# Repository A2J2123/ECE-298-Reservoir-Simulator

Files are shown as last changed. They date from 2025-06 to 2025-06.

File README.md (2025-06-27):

# ECE-298 Reservoir Simulator

A comprehensive reservoir simulator system designed and built using an STM32 Nucleo board to emulate water flow management in a controlled reservoir environment.

---

## 🏗️ What is this project?

This project features a fully integrated reservoir simulation platform that:

- Measures real-time water level and displays the percentage full.
- Controls water flow direction and simulates water pumping.
- Monitors pump speed, indicates flow direction, and transmits live measurements to a computer via UART.
- Models practical water management and feedback control scenarios using embedded systems.

---

## ⚙️ How does it work?

The simulator is powered by an STM32 microcontroller, programmed in C, and incorporates:

- **Servo Motor:** Controls flow direction (simulates outlet switching).
- **DC Motor:** Drives the water pump, with speed monitored by an RPM sensor.
- **Ultrasonic Sensor:** Measures water level with high accuracy.
- **RGB LED:** Provides visual status indicators.
- **Custom Timer PCB:** Drives a seven-segment display for real-time feedback.
- **UART Connection:** Streams sensor data and system state to a computer for monitoring and analysis.

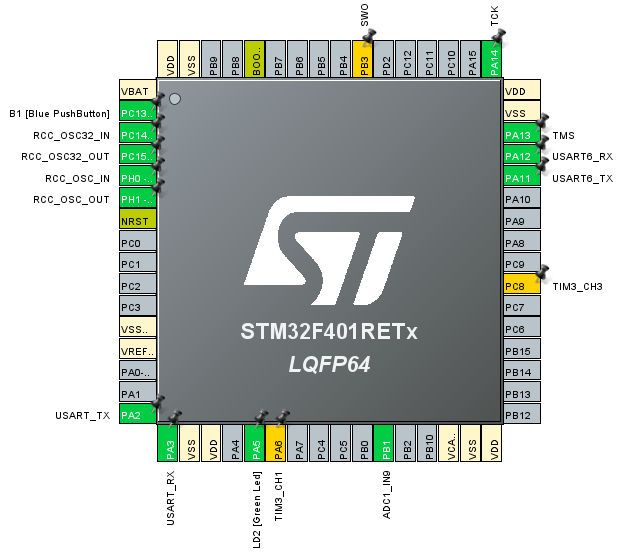
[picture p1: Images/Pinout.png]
STM32 Pinout Diagram

*STM32F401RETx microcontroller pinout used as the system's central unit.*

---

## 🖥️ System Architecture

- **Embedded C Code:** Collects and processes sensor data, manages actuator control, and implements feedback logic for accurate reservoir simulation.
- **Real-Time Feedback:** Water level, flow direction, and pump speed are displayed and logged for live monitoring.

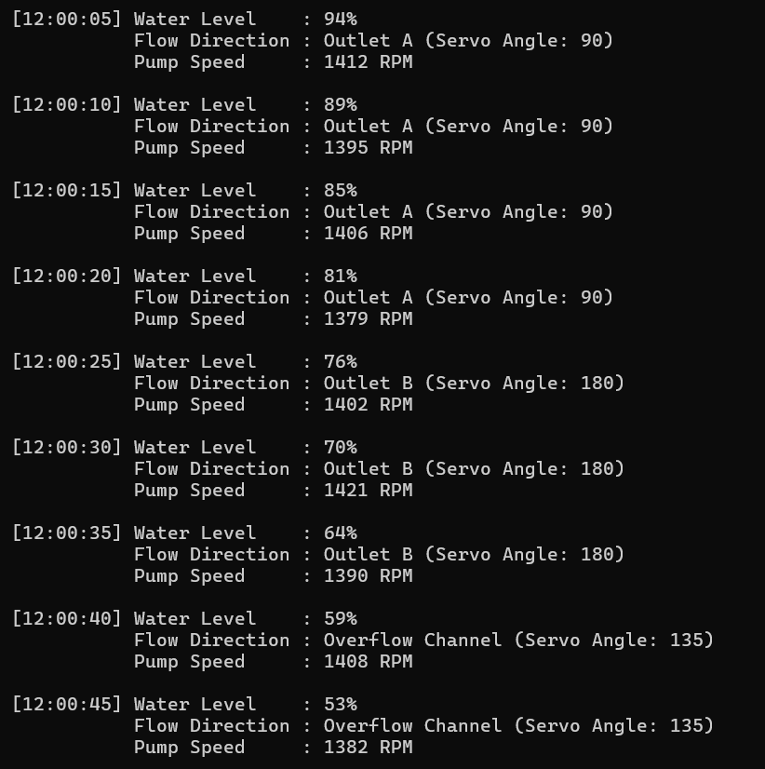
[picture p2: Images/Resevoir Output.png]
Live UART Output Sample

*Example of real-time UART output: water level, flow direction, and pump speed logged at regular intervals.*

---

## 🛠️ Hardware Overview

### Components
- STM32 Nucleo Board (F401RE)
- Servo Motor
- DC Motor
- Ultrasonic Distance Sensor (HC-SR04)
- RPM Speed Sensor
- RGB LED
- Custom Timer PCB for seven-segment display
- Breadboard, jumper wires, and supporting electronics

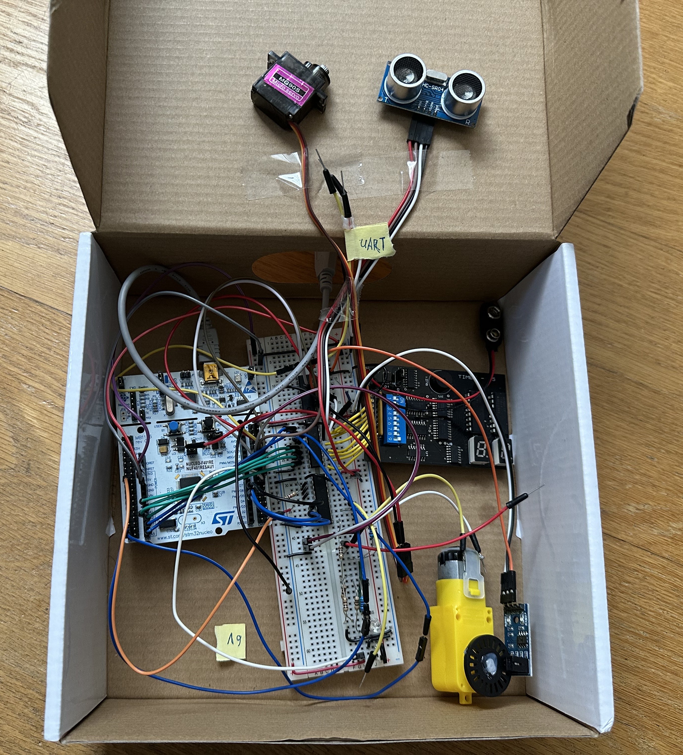
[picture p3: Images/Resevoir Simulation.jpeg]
System Prototype

*Hardware setup: STM32 Nucleo board, custom PCB, sensors, and actuators assembled for simulation.*

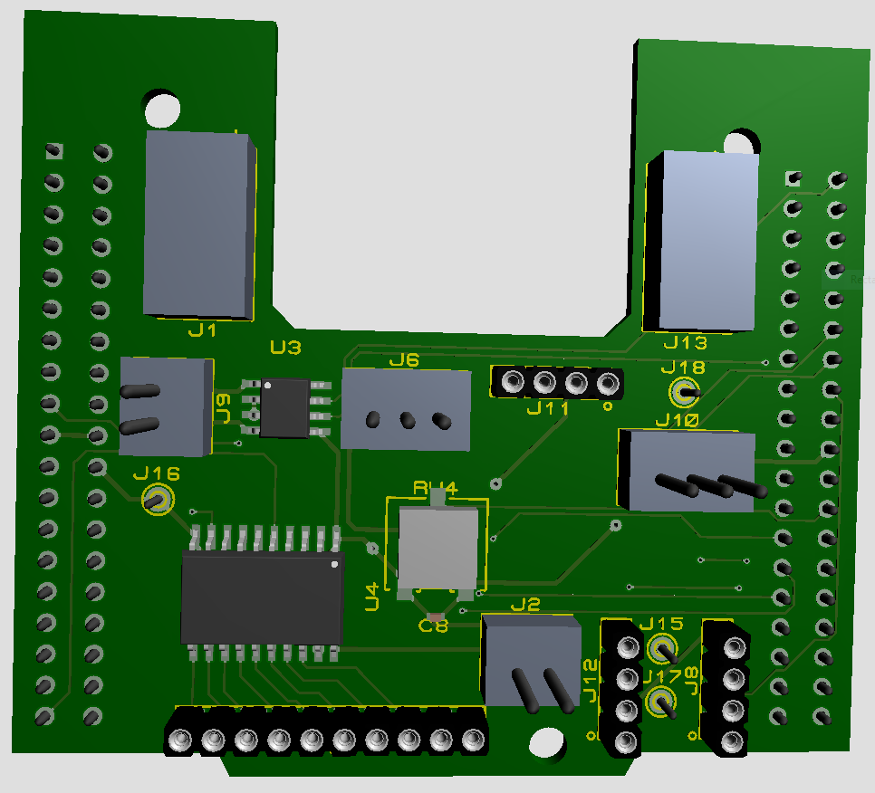
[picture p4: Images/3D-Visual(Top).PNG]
Custom Timer PCB

*Custom-designed PCB for accurate timer and display control.*

---

## 🏆 Results

- Achieved a **fully functional reservoir simulator** capable of displaying real-time water level percentage and simulating advanced flow control.
- Enabled **accurate and responsive feedback** on reservoir conditions using integrated sensor data, motor control, and UART communication.
- Demonstrated **effective integration of embedded systems** with sensors and actuators for hands-on modeling of practical water management.

---

## 📦 Repository Structure

- `/src` — Source code for STM32 (C)
- `/hardware` — Schematics, PCB design files, and hardware diagrams
- `/docs` — Additional documentation and test results
- `/images` — Project photos and diagrams

---

## 💡 Key Features

- Real-time water level measurement and display
- Dynamic flow direction control via servo motor
- Pump speed monitoring and feedback
- UART-based data transmission for live system monitoring
- Modular hardware for rapid prototyping and testing

---

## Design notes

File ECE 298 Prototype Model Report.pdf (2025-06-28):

# ECE 298 Prototype Model Report

Lab Section: | 001 | Team No: | 10 | Date: | 2024-12-03
Student 1 Name: | Dwayne Burton | | | ID: | d4burton
Student 2 Name: | Aundre Jeganathan | | | ID: | am2jegan

# ECE298 RESERVOIR SYSTEM ADAPTER

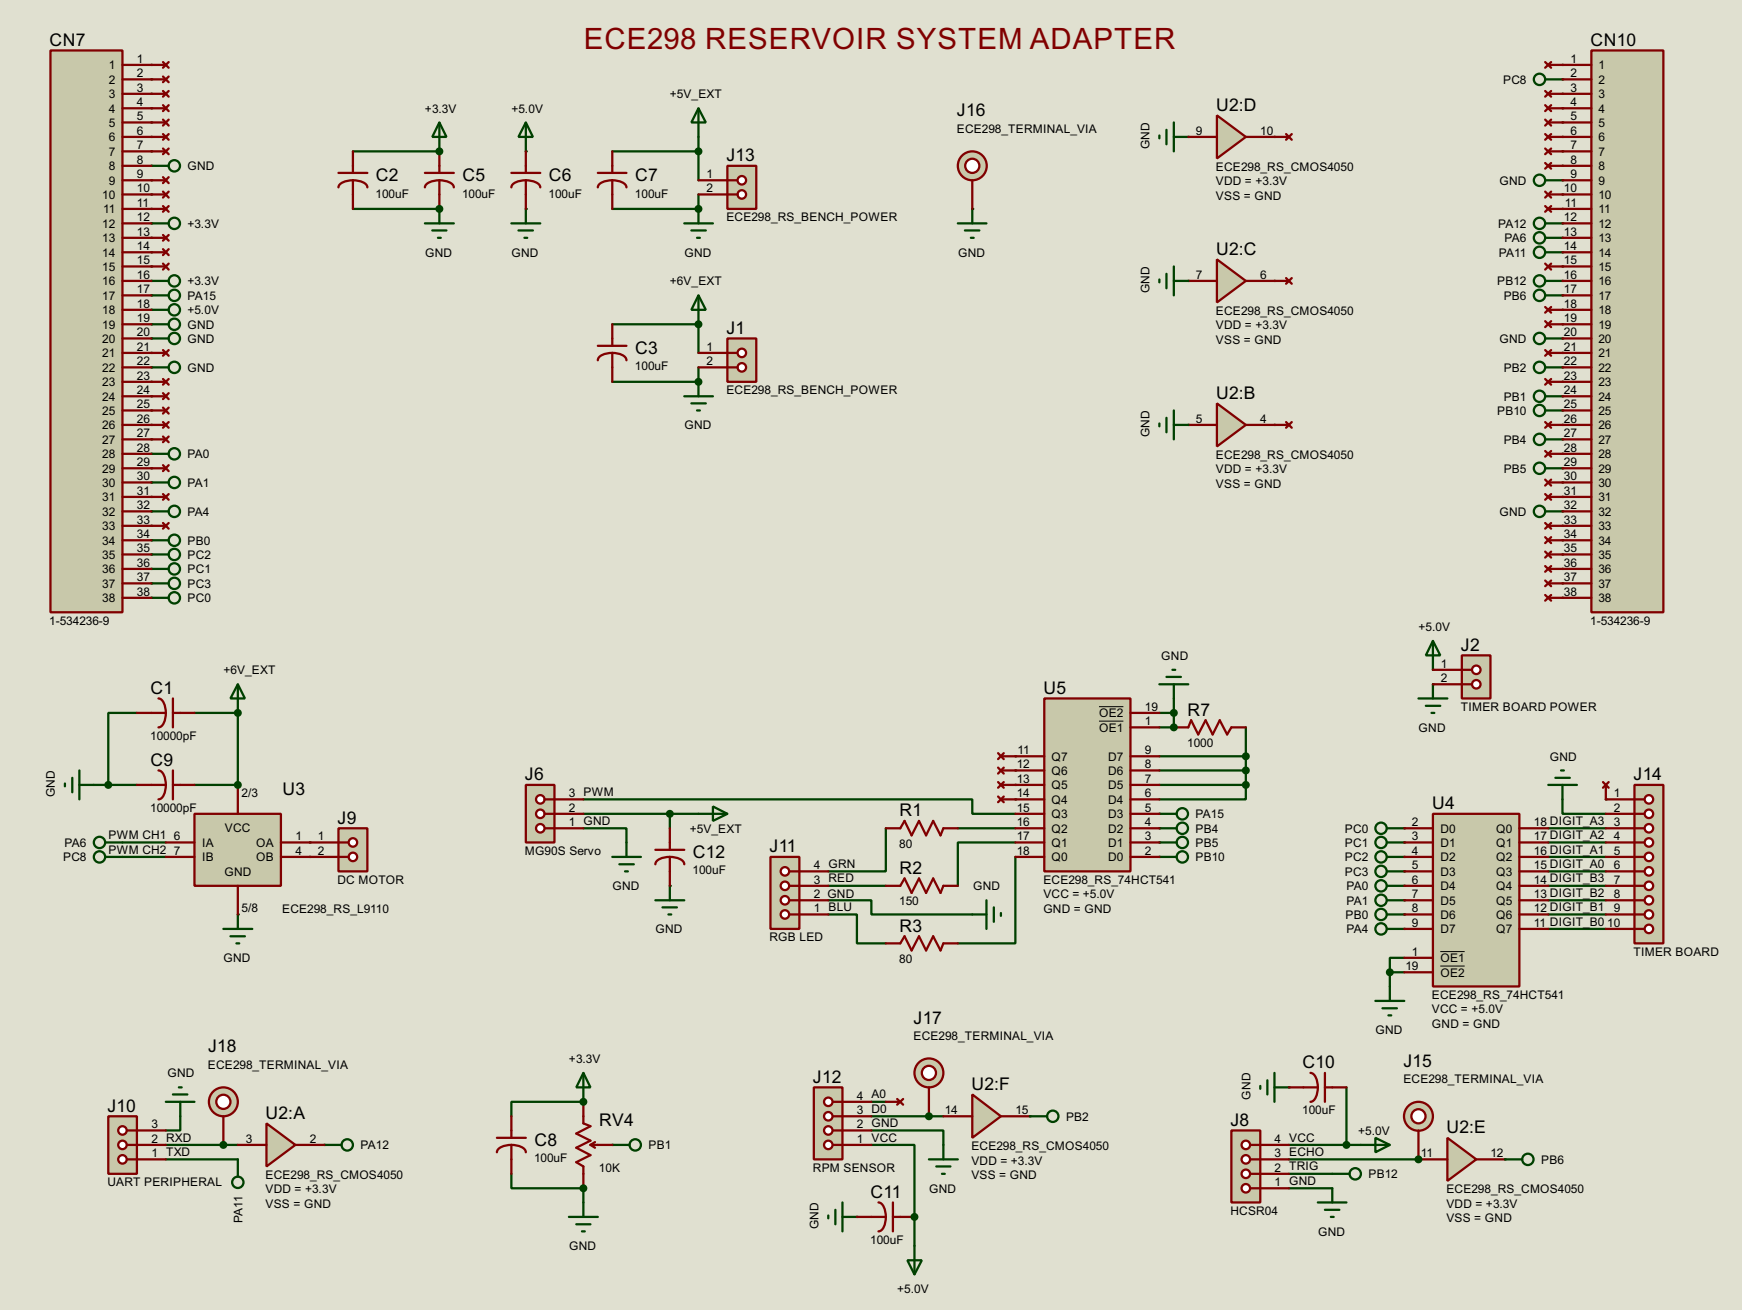
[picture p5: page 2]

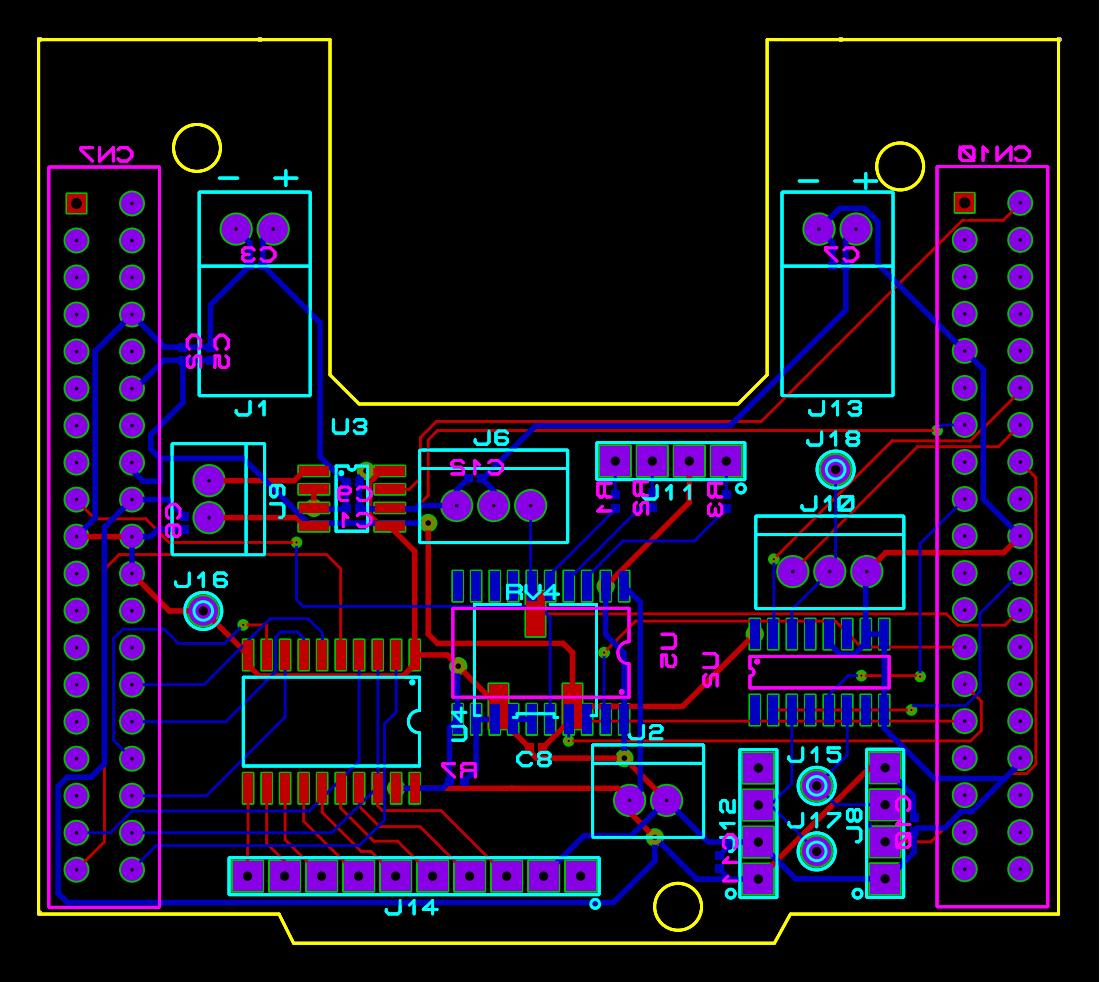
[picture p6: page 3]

# NETLIST:

ISIS SCHEMATIC DESCRIPTION FORMAT 8.0 ===================================== Design: ECE298_RS_ADAPTER
Doc. no.: <NONE>
Revision: <NONE>
Author: <NONE>
Created: 2023-07-07
Modified: 2024-11-30

*PROPERTIES,0

*MODELDEFS,0

*PARTLIST,36
C1,ECE298_RS_CAP_0U1,10000pF,CODE="Digikey PCC103BQDKR-ND",EID=1E,PACKAGE=CAPC1005X55 C2,ECE298_RS_CAP_0U1,100uF,CODE="Digikey PCC103BQDKR-ND",EID=1F,PACKAGE=CAPC1005X55 C3,ECE298_RS_CAP_0U1,100uF,CODE="Digikey PCC103BQDKR-ND",EID=3,PACKAGE=CAPC1005X55 C5,ECE298_RS_CAP_0U1,100uF,CODE="Digikey PCC103BQDKR-ND",EID=4,PACKAGE=CAPC1005X55 C6,ECE298_RS_CAP_0U1,100uF,CODE="Digikey PCC103BQDKR-ND",EID=5,PACKAGE=CAPC1005X55 C7,ECE298_RS_CAP_0U1,100uF,CODE="Digikey PCC103BQDKR-ND",EID=E,PACKAGE=CAPC1005X55 C8,ECE298_RS_CAP_0U1,100uF,CODE="Digikey PCC103BQDKR-ND",EID=11,PACKAGE=CAPC1005X55 C9,ECE298_RS_CAP_0U1,10000pF,CODE="Digikey PCC103BQDKR-ND",EID=12,PACKAGE=CAPC1005X55 C10,ECE298_RS_CAP_0U1,100uF,CODE="Digikey PCC103BQDKR-ND",EID=13,PACKAGE=CAPC1005X55 C11,ECE298_RS_CAP_0U1,100uF,CODE="Digikey PCC103BQDKR-ND",EID=14,PACKAGE=CAPC1005X55 C12,ECE298_RS_CAP_0U1,100uF,CODE="Digikey PCC103BQDKR-ND",EID=15,PACKAGE=CAPC1005X55 CN7,1-534236-9,1-534236-9,CODE=1-534236-9,EID=25,PACKAGE=ECE298_REVTRANS38DIL-1,SUPPLIER=TE_CONNECTIVITY CN10,1-534236-9,1-534236-9,CODE=1-534236-9,EID=29,PACKAGE=ECE298_REVTRANS38DIL-1,SUPPLIER=TE_CONNECTIVITY J1,ECE298_RS_BENCH_POWER,ECE298_RS_BENCH_POWER,EID=1D,PACKAGE=SIL-100-02R J2,ECE298_RS_2PINHDR,"TIMER BOARD POWER",EID=20,PACKAGE=SIL-100-02
J6,ECE298_RS_3PINHDR,"MG90S Servo",EID=6,PACKAGE=SIL-100-03 J8,ECE298_RS_4PINREC,HCSR04,EID=7,PACKAGE=CONN-SIL4 J9,ECE298_RS_2PINHDR,"DC MOTOR",EID=8,PACKAGE=SIL-100-02 J10,ECE298_RS_3PINHDR,"UART PERIPHERAL",EID=B,PACKAGE=SIL-100-03 J11,ECE298_RS_4PINREC,"RGB LED",EID=C,PACKAGE=CONN-SIL4 J12,ECE298_RS_4PINREC,"RPM SENSOR",EID=D,PACKAGE=CONN-SIL4 J13,ECE298_RS_BENCH_POWER,ECE298_RS_BENCH_POWER,EID=F,PACKAGE=SIL-100-02R J14,ECE298_RS_10PINREC,"TIMER BOARD",EID=10,PACKAGE=CONN-SIL10 J15,ECE298_TERMINAL_VIA,ECE298_TERMINAL_VIA,EID=17,PACKAGE=PIN J16,ECE298_TERMINAL_VIA,ECE298_TERMINAL_VIA,EID=18,PACKAGE=PIN J17,ECE298_TERMINAL_VIA,ECE298_TERMINAL_VIA,EID=19,PACKAGE=PIN J18,ECE298_TERMINAL_VIA,ECE298_TERMINAL_VIA,EID=1A,PACKAGE=PIN R1,9C04021A1500JLHF3,80,CODE="Digikey 311-150JDKR-ND",EID=1,PACKAGE=RESC1005X40,PRIMTYPE=RESISTOR R2,9C04021A1800JLHF3,150,CODE="Digikey 311-180JCT-ND",EID=2,PACKAGE=RESC1005X40,PRIMTYPE=RESISTOR R3,9C04021A1500JLHF3,80,CODE="Digikey 311-150JDKR-ND",EID=24,PACKAGE=RESC1005X40,PRIMTYPE=RESISTOR
R7,9C04021A1500JLHF3,1000,CODE="Digikey 311-150JDKR-ND",EID=1B,PACKAGE=RESC1005X40,PRIMTYPE=RESISTOR
RV4,ECE298_RS_POT10K,10K,CODE="Digikey 3361P-103GLFDKR-ND",EID=9,PACKAGE=TRIM_3361P,STATE=5 U2,ECE298_RS_CMOS4050,ECE298_RS_CMOS4050,EID_A=21,EID_B=22,EID_C=23,EID_D=26,EID_E=27,EID_F=28,ITFMOD=CMOS,MODFILE=40BUF,PACKAGE=SO16,VDD=+3 .3V,VSS=GND
U3,ECE298_RS_L9110,ECE298_RS_L9110,EID=A,ITFMOD=TTL,PACKAGE=SO8 U4,ECE298_RS_74HCT541,ECE298_RS_74HCT541,EID=16,GND=GND,PACKAGE=SO20W,PINSWAP="1,19",VCC=+5.0V U5,ECE298_RS_74HCT541,ECE298_RS_74HCT541,EID=1C,GND=GND,PACKAGE=SO20W,PINSWAP="1,19",VCC=+5.0V

*NETLIST,47
GRN,3,CLASS=SIGNAL
GRN,LBL
R1,PS,1
J11,PS,4

GRN_5V,3,CLASS=SIGNAL
GRN_5V,LBL

R1,PS,2
U5,TS,16

RED,3,CLASS=SIGNAL
RED,LBL
R2,PS,1
J11,PS,3

RED_5V,3,CLASS=SIGNAL
RED_5V,LBL
R2,PS,2
U5,TS,17

PWM,3,CLASS=SIGNAL
PWM,LBL
J6,PS,3
U5,TS,15

ECHO,4,CLASS=SIGNAL
ECHO,LBL
J8,PS,3
J15,PS,1
U2,IP,11

OA,3,CLASS=POWER
OA,LBL
J9,PS,1
U3,OP,1

OB,3,CLASS=POWER
OB,LBL
J9,PS,2
U3,OP,4

RXD,4,CLASS=SIGNAL
RXD,LBL
J10,PS,2
U2,IP,3
J18,PS,1

BLU,3,CLASS=SIGNAL
BLU,LBL
J11,PS,1
R3,PS,1

D0,4,CLASS=SIGNAL
D0,LBL
J12,PS,3
J17,PS,1
U2,IP,14

DIGIT_A3,3,CLASS=SIGNAL
DIGIT_A3,LBL
U4,TS,18
J14,PS,3

DIGIT_A2,3,CLASS=SIGNAL
DIGIT_A2,LBL
U4,TS,17
J14,PS,4

DIGIT_A1,3,CLASS=SIGNAL

DIGIT_A1,LBL
U4,TS,16
J14,PS,5

DIGIT_A0,3,CLASS=SIGNAL
DIGIT_A0,LBL
U4,TS,15
J14,PS,6

DIGIT_B3,3,CLASS=SIGNAL
DIGIT_B3,LBL
U4,TS,14
J14,PS,7

DIGIT_B2,3,CLASS=SIGNAL
DIGIT_B2,LBL
U4,TS,13
J14,PS,8

DIGIT_B1,3,CLASS=SIGNAL
DIGIT_B1,LBL
U4,TS,12
J14,PS,9

DIGIT_B0,3,CLASS=SIGNAL
DIGIT_B0,LBL
U4,TS,11
J14,PS,10

DRAIN,6,CLASS=POWER
DRAIN,LBL
R7,PS,1
U5,IP,6
U5,IP,7
U5,IP,8
U5,IP,9

BLU_5V,3,CLASS=SIGNAL
BLU_5V,LBL
U5,TS,18
R3,PS,2

PA0,3,CLASS=SIGNAL
PA0,GT
CN7,PS,28
U4,IP,6

PA1,3,CLASS=SIGNAL
PA1,GT
CN7,PS,30
U4,IP,7

PA4,3,CLASS=SIGNAL
PA4,GT
CN7,PS,32
U4,IP,9

PB0,3,CLASS=SIGNAL
PB0,GT
CN7,PS,34
U4,IP,8

PC2,3,CLASS=SIGNAL
PC2,GT
CN7,PS,35
U4,IP,4

PC1,3,CLASS=SIGNAL
PC1,GT
CN7,PS,36
U4,IP,3

PC3,3,CLASS=SIGNAL
PC3,GT
CN7,PS,37
U4,IP,5

PC0,3,CLASS=SIGNAL
PC0,GT
CN7,PS,38
U4,IP,2

PA12,3,CLASS=SIGNAL
PA12,GT
CN10,PS,12
U2,OP,2

PA6,4,CLASS=SIGNAL
PA6,GT
PWM CH1,LBL
CN10,PS,13
U3,IP,6

PA11,4,CLASS=SIGNAL
PA11,GT
TXD,LBL
CN10,PS,14
J10,PS,1

PB12,4,CLASS=SIGNAL
PB12,GT
TRIG,LBL
CN10,PS,16
J8,PS,2

PC8,4,CLASS=SIGNAL
PC8,GT
PWM CH2,LBL
CN10,PS,2
U3,IP,7

PB1,3,CLASS=SIGNAL
PB1,GT
CN10,PS,24
RV4,PS,3

PB10,3,CLASS=SIGNAL
PB10,GT
CN10,PS,25
U5,IP,2

PB4,3,CLASS=SIGNAL
PB4,GT
CN10,PS,27

U5,IP,4

PB5,3,CLASS=SIGNAL
PB5,GT
CN10,PS,29
U5,IP,3

PA15,3,CLASS=SIGNAL
PA15,GT
CN7,PS,17
U5,IP,5

PB2,3,CLASS=SIGNAL
PB2,GT
U2,OP,15
CN10,PS,22

PB6,3,CLASS=SIGNAL
PB6,GT
U2,OP,12
CN10,PS,17

{NC},58
A0,LBL
J14,PS,1
U2,PS,13
U2,PS,16
U2,OP,6
U2,OP,4
CN10,PS,31
U2,OP,10
CN10,PS,15
CN10,PS,37
CN10,PS,35
CN10,PS,34
CN10,PS,30
CN10,PS,28
CN10,PS,33
CN10,PS,26
CN10,PS,23
CN10,PS,21
CN10,PS,19
CN10,PS,18
CN10,PS,11
CN10,PS,6
CN10,PS,5
CN10,PS,4
CN10,PS,3
CN10,PS,1
CN7,PS,1
CN7,PS,2
CN7,PS,3
CN7,PS,13
CN7,PS,15
CN7,PS,21
CN7,PS,23
CN7,PS,14
CN10,PS,8
CN10,PS,7
CN10,PS,38
CN10,PS,36
CN10,PS,10

CN7,PS,9
CN7,PS,7
CN7,PS,6
CN7,PS,5
CN7,PS,4
CN7,PS,33
CN7,PS,31
CN7,PS,29
CN7,PS,27
CN7,PS,26
CN7,PS,25
CN7,PS,24
CN7,PS,11
CN7,PS,10
U5,TS,14
U5,TS,13
U5,TS,12
U5,TS,11
J12,PS,4

+3.3V,8,CLASS=POWER
+3.3V,PR
U2,PP,1
CN7,PS,16
CN7,PS,12
C8,PS,1
RV4,PS,2
C5,PS,1
C2,PS,1

+5.0V,11,CLASS=POWER
+5.0V,PR
VCC,LBL
CN7,PS,18
J2,PS,1
U5,PP,20
U4,PP,20
J12,PS,1
C11,PS,1
J8,PS,4
C10,PS,1
C6,PS,1

+5V_EXT,5,CLASS=POWER
+5V_EXT,PR
J13,PS,1
C7,PS,1
J6,PS,2
C12,PS,1

+6V_EXT,7,CLASS=POWER
+6V_EXT,PR
U3,PP,2
U3,PP,3
C9,PS,1
C1,PS,1
J1,PS,1
C3,PS,1

GND,43,CLASS=POWER
GND,PR
J14,PS,2

U2,PP,8
U2,IP,7
U2,IP,5
U2,IP,9
CN10,PS,9
CN10,PS,32
CN10,PS,20
CN7,PS,8
CN7,PS,22
CN7,PS,20
CN7,PS,19
J2,PS,2
U5,PP,10
J16,PS,1
U4,PP,10
C12,PS,2
U5,IP,19
U5,IP,1
R7,PS,2
C11,PS,2
C10,PS,2
C9,PS,2
C1,PS,2
U4,IP,1
U4,IP,19
J13,PS,2
C7,PS,2
J12,PS,2
J11,PS,2
J10,PS,3
J8,PS,1
U3,PP,5
U3,PP,8
C8,PS,2
RV4,PS,1
J6,PS,1
C6,PS,2
C5,PS,2
C2,PS,2
C3,PS,2
J1,PS,2

# Pre-Production Check:

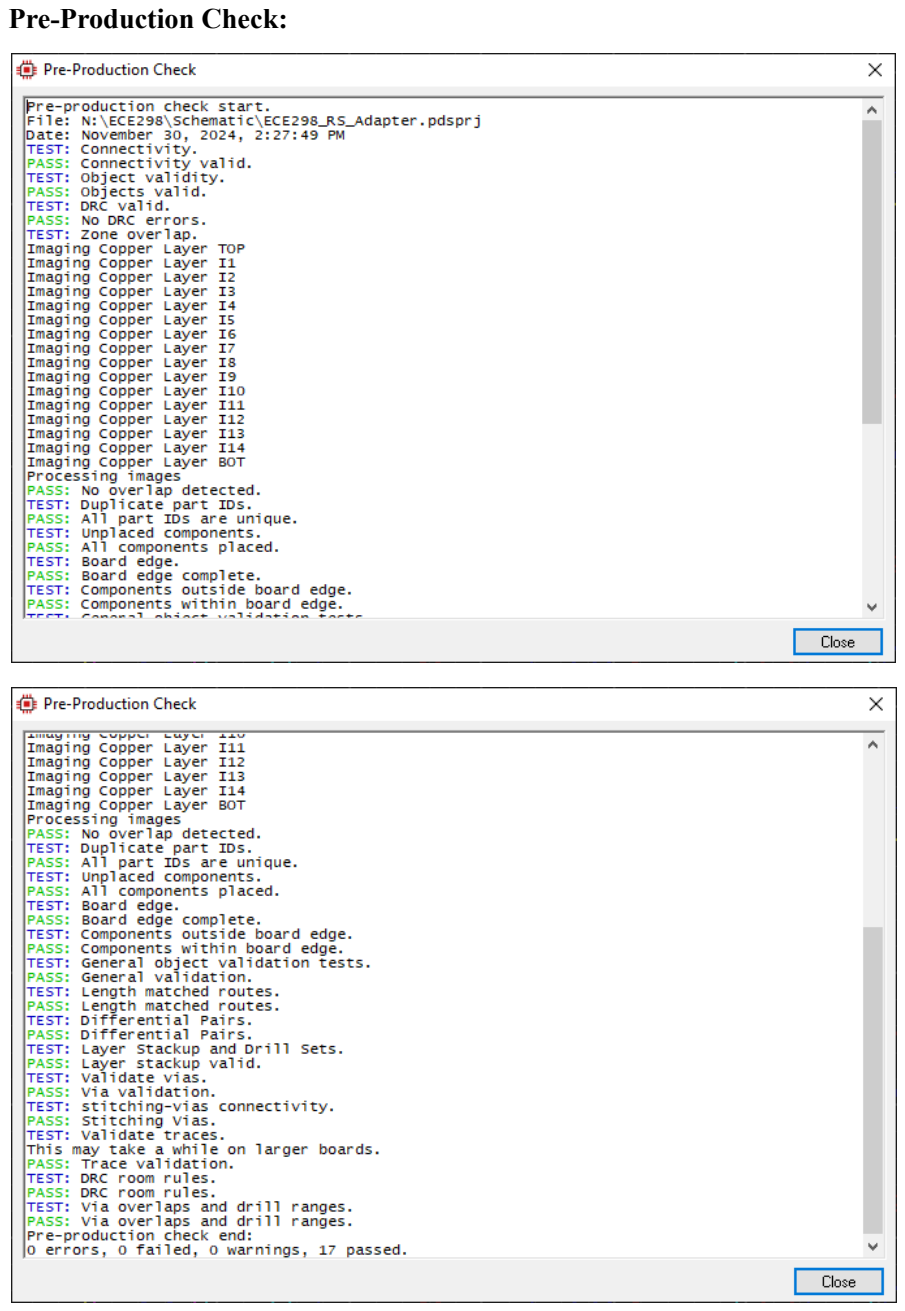
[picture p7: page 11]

Part ID | Value | Package | Stock Code Layer | Rotation | X
CN7 | 1-534236-9 ECE298_REVTRANS38DIL-1 1-534236-9 BOT | 0 | 177.362
CN10 | 1-534236-9 ECE298_REVTRANS38DIL-1 1-534236-9 BOT | 0 | 2577.36
J14 | TIMER BOARDCONN-SIL10 | TOP | 180 | 1014.57
J1 | ECE298_RS_BENCH_POWER SIL-100-02R | TOP | 180 | 583.858
J6 | MG90S ServoSIL-100-03 | TOP | 0 | 1229.72
J9 | DC MOTOR SIL-100-02 | TOP | 270 | 460.63
J11 | RGB LED | CONN-SIL4 | TOP | 180 | 1708.46
J10 | UART PERIPHERAL SIL-100-03 | TOP | 0 | 2137.8
J8 | HCSR04 | CONN-SIL4 | TOP | 90 | 2287.4
J2 | TIMER BOARD POWER SIL-100-02 | TOP | 0 | 1646.85
J12 | RPM SENSORCONN-SIL4 | TOP | 90 | 1944.88
J13 | ECE298_RS_BENCH_POWER SIL-100-02R | TOP | 180 | 2158.66
RV4 | 10K | TRIM_3361P Digikey 3361P-103GLFDKR-ND TOP | 0 | 1342.52
U2 | ECE298_RS_CMOS4050 SO16 | BOT | 90 | 2110.24
U5 | ECE298_RS_74HCT541 SO20W | BOT | 270 | 1357.28
R1 | 80 RESC1005X40Digikey 311-150JDKR-ND BOT | 90 | 1559.06
R2 | 150 RESC1005X40Digikey 311-180JCT-ND BOT | 90 | 1657.48
R3 | 80 RESC1005X40Digikey 311-150JDKR-ND BOT | 90 | 1858.27
U4 | ECE298_RS_74HCT541 SO20W | TOP | -90 | 791.339
U3 | ECE298_RS_L9110 SO8 | TOP | 0 | 846.457
C1 | 10000pF | CAPC1005X55Digikey PCC103BQDKR-ND BOT | 180 | 848.425
C9 | 10000pF | CAPC1005X55Digikey PCC103BQDKR-ND BOT | 180 | 848.425
C2 | 100uF | CAPC1005X55Digikey PCC103BQDKR-ND BOT | -90 | 389.764
C5 | 100uF | CAPC1005X55Digikey PCC103BQDKR-ND BOT | -90 | 464.567
C6 | 100uF | CAPC1005X55Digikey PCC103BQDKR-ND BOT | 90 | 393.701
C7 | 100uF | CAPC1005X55Digikey PCC103BQDKR-ND BOT | 0 | 2163.39
C3 | 100uF | CAPC1005X55Digikey PCC103BQDKR-ND BOT | 0 | 588.583
R7 | 1000 RESC1005X40Digikey 311-150JDKR-ND BOT | 0 | 1129.92
C8 | 100uF | CAPC1005X55Digikey PCC103BQDKR-ND TOP | 180 | 1344.49
C10 | 100uF | CAPC1005X55Digikey PCC103BQDKR-ND BOT | 90 | 2366.14
C11 | 100uF | CAPC1005X55Digikey PCC103BQDKR-ND BOT | 270 | 1838.58
J15 | ECE298_TERMINAL_VIA PIN | TOP | 0 | 2102.36
J17 | ECE298_TERMINAL_VIA PIN | TOP | 0 | 2102.36
J18 | ECE298_TERMINAL_VIA PIN | TOP | 0 | 2153.54
J16 | ECE298_TERMINAL_VIA PIN | TOP | 0 | 444.882
C12 | 100uF | CAPC1005X55Digikey PCC103BQDKR-ND BOT | 0 | 1179.13

Y
1019.69
1021.26
102.362
1850.39
1103.46
1120.87
1223.31
925.197
245.276
307.087
244.488
1850.39
686.024
653.543
705.827
1114.17
1118.11
1114.17
519.685
1122.05
1094.49
1165.35
1513.78
1513.78
1057.09
1751.97
1751.97
358.268
448.819
242.126
139.764
346.457
169.291
1200.79
818.898
1177.17

# Bill Of Materials for ECE298_RS_ADAPTER

Design Title | ECE298_RS_ADAPTER

# Author Document Number Revision

Design Created | July 7, 2023

# Design Last Modified November 30, 2024 Total Parts In Design 36

# 11 Capacitors

Quantity | References | Value
2 | C1,C9 | 10000pF
9 | C2-C3,C5-C8,C10-C12 | 100uF

## Sub-totals:

# 4 Resistors

Quantity | References | Value
2 | R1,R3 | 80
1 | R2 | 150
1 | R7 | 1000

## Sub-totals:

# 4 Integrated Circuits

Quantity | References | Value
1 | U2 | ECE298_RS_CMOS4050
1 | U3 | ECE298_RS_L9110
2 | U4-U5 | ECE298_RS_74HCT541

## Sub-totals:

# 17 Miscellaneous

Quantity | References | Value
2 | CN7,CN10 | 1-534236-9
2 | J1,J13 | ECE298_RS_BENCH_POWER
1 | J2 | TIMER BOARD POWER
1 | J6 | MG90S Servo
1 | J8 | HCSR04
1 | J9 | DC MOTOR
1 | J10 | UARTPERIPHERAL
1 | J11 | RGB LED
1 | J12 | RPM SENSOR
1 | J14 | TIMER BOARD
4 | J15-J18 | ECE298_TERMINAL_VIA
1 | RV4 | 10K

## Sub-totals:

## Totals:

| | November 30, 2024 2:31:16 PM

# 3D Views of Top and Bottom PCB Assembly:

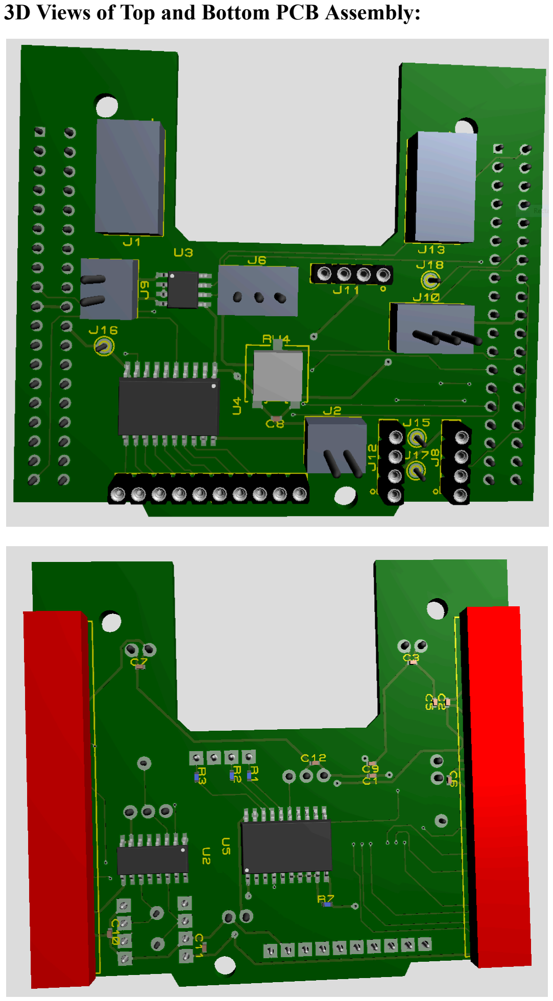
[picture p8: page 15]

# Gerber Layers:

# Copper:

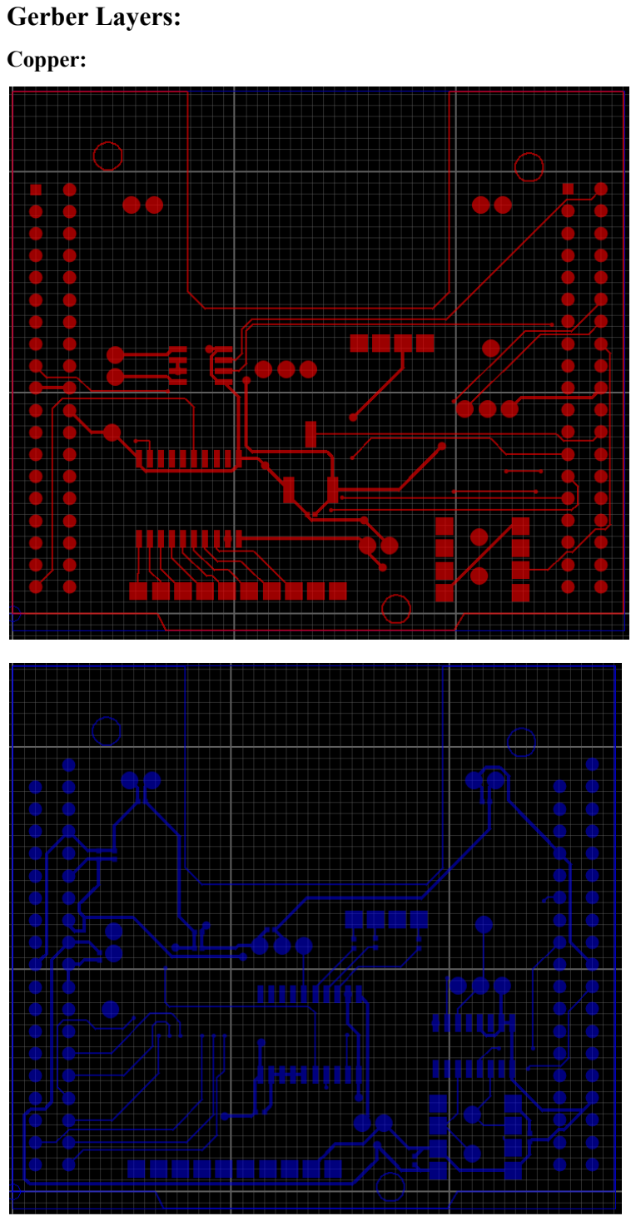
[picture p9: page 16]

# Silkscreen:

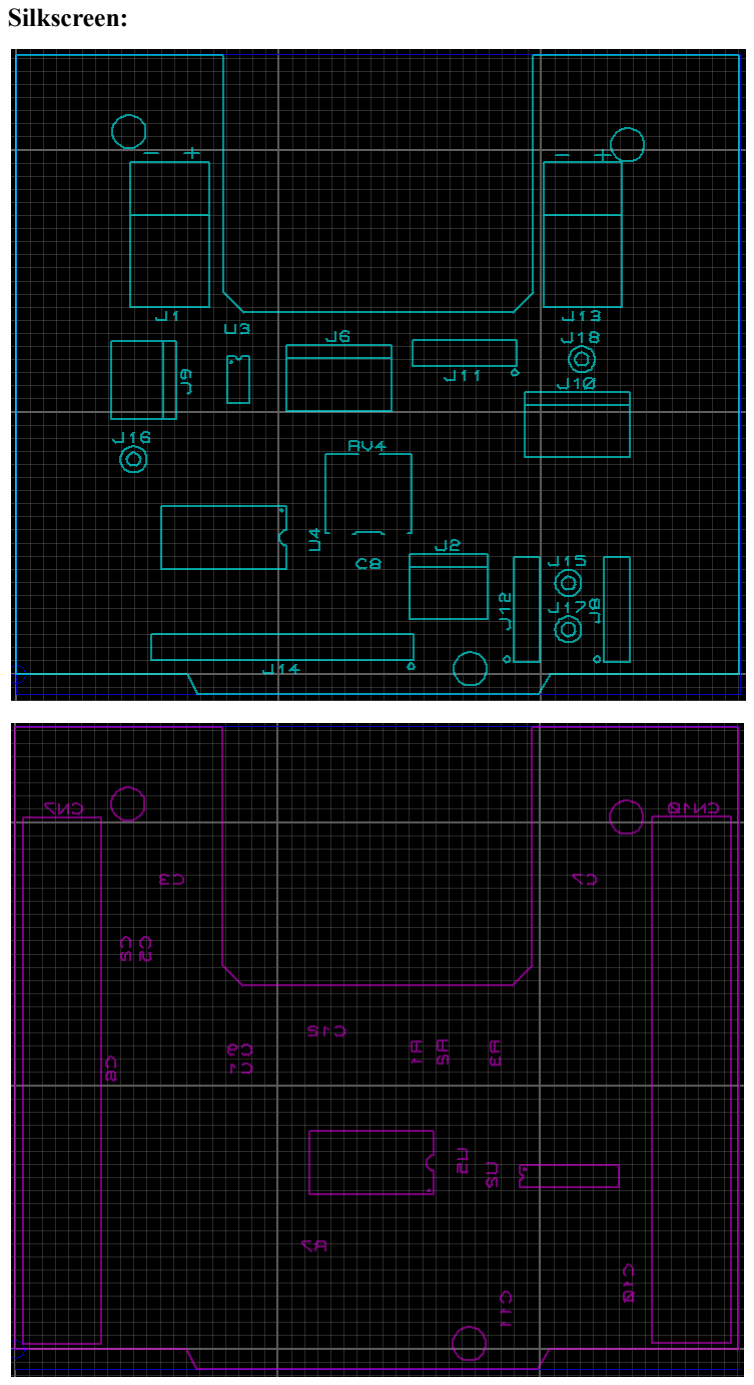
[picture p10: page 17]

# Mask (Solder Resist):

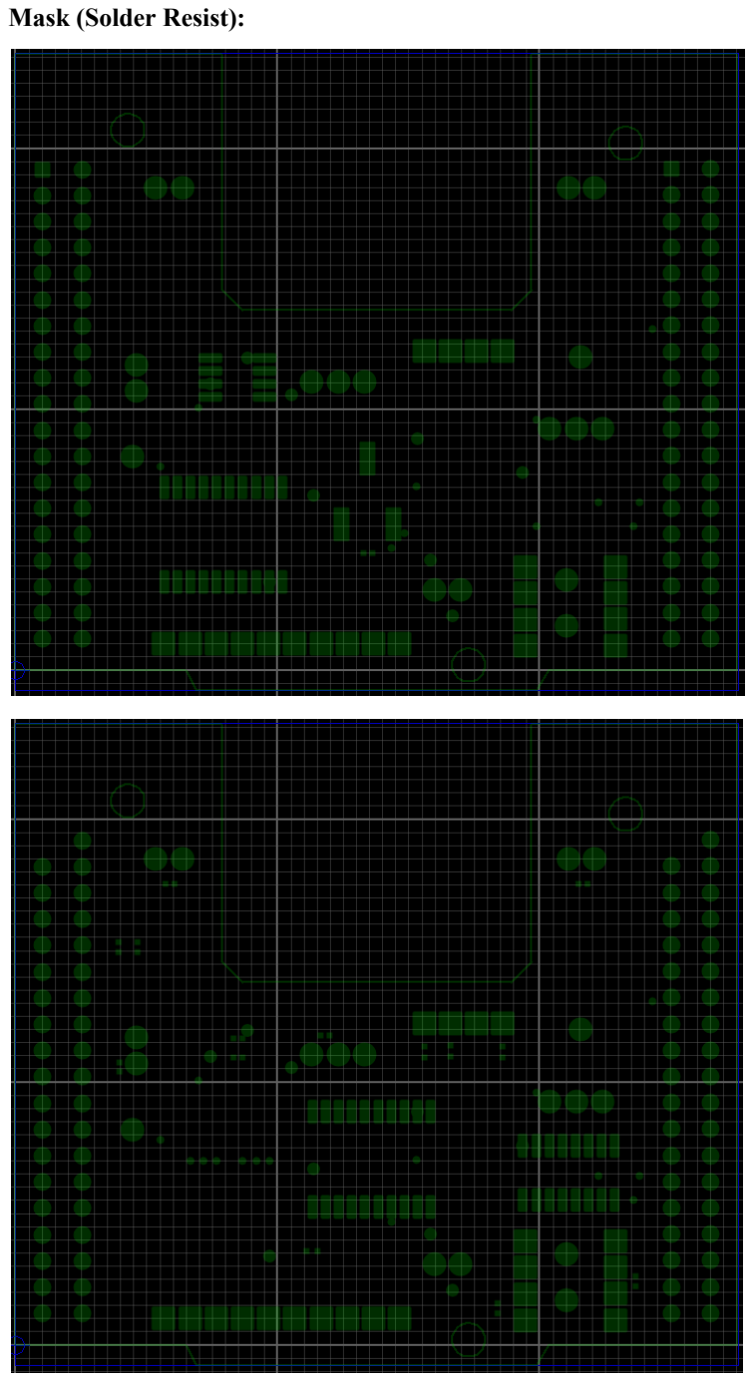
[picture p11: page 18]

# Paste Layer:

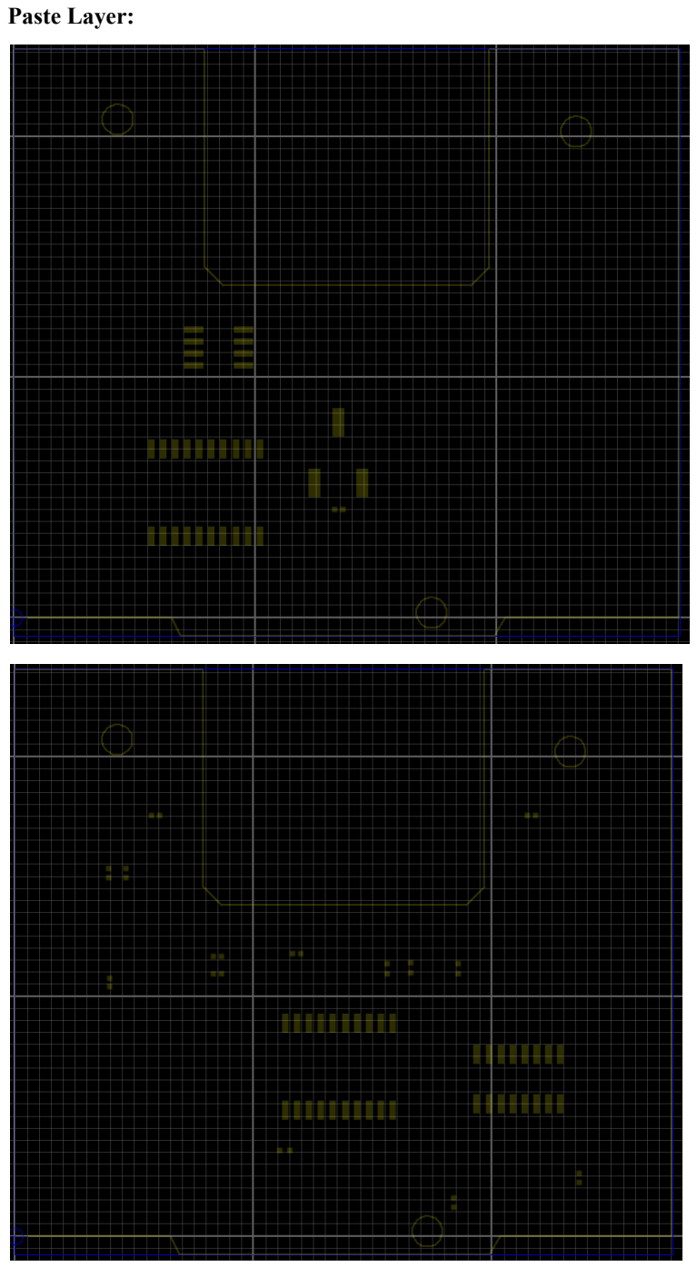
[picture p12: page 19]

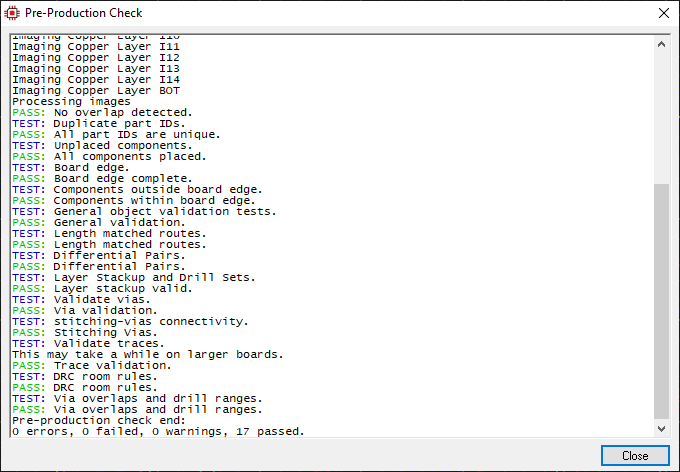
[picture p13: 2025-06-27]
Hardware/Production Check/Pre-Production(2).PNG

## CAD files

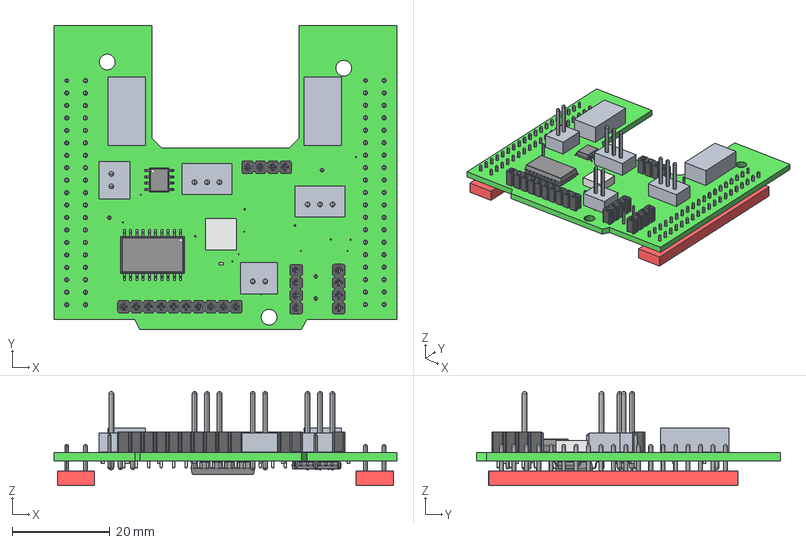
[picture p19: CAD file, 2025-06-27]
Hardware/ECE298_RS_Adapter.STEP
70.0 x 62.0 x 19.2 mm
Layer_1
Pin_1 x 16
Pin_2 x 12
Pin_3 x 4
Pin_4 x 2
Pin_5 x 2
Pin_6 x 2
Pin_7 x 2
Pin_8 x 2
Pin_9 x 2
Pin_10 x 2
Pin_11 x 2
Pin_12 x 2
Pin_13 x 2
Pin_14 x 2
Pin_15 x 2
Pin_16 x 2
Pin_17 x 2
Pin_18 x 2
Pin_19 x 2
Pin_20 x 2
Pin_21 x 2
Pin_22 x 2
Pin_23 x 2
Pin_24 x 2
Pin_25 x 2
Pin_26 x 2
Pin_27 x 2
Pin_28 x 2
Pin_29 x 2
Pin_30 x 2
Pin_31 x 2
Pin_32 x 2
Pin_33 x 2
Pin_34 x 2
Pin_35 x 2
Pin_36 x 2
Pin_37 x 2
Pin_38 x 2

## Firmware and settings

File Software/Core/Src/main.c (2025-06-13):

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
/* Includes ------------------------------------------------------------------*/
#include "main.h"

/* USER CODE BEGIN Includes */
#include <string.h>
#include <stdio.h>
#include <time.h>
#include <stdlib.h>
/* USER CODE END Includes */

ADC_HandleTypeDef hadc1;

TIM_HandleTypeDef htim2;
TIM_HandleTypeDef htim3;
TIM_HandleTypeDef htim4;
TIM_HandleTypeDef htim5;

UART_HandleTypeDef huart2;
UART_HandleTypeDef huart6;

/* USER CODE BEGIN PV */
volatile uint8_t clock_hours = 0;
volatile uint8_t clock_mins = 0;
volatile uint8_t clock_secs = 0;
volatile uint8_t wall_clock_hr_update_flag = 0;

volatile uint8_t hcsr04_Rx_flag = 0; // Reset the interrupt flag for the HCSR04
volatile uint8_t first_edge = 0; // Set it back to false
volatile uint16_t time_edge1 = 0;
volatile uint16_t time_edge2 = 0;

volatile uint16_t rpm_tick_count = 0;

uint8_t empty = 0;
uint8_t byte[2];
uint8_t rcv_intpt_flag = 0;
uint8_t txd_msg_buffer[64] = {0};

uint16_t time_diff = 0;
int filled = 0;
int distance = 0;

uint8_t counter_tens = 0;
uint8_t counter_ones = 0;
uint8_t bottom_distance = 65; //distance to bottom in cm
uint8_t top_distance = 10; //distance to top in cm
uint8_t rpm = 0;

int TIM2_CH1_DCVAL = 500;

/* USER CODE END PV */

void SystemClock_Config(void);
static void MX_GPIO_Init(void);
static void MX_USART2_UART_Init(void);
static void MX_USART6_UART_Init(void);
static void MX_ADC1_Init(void);
static void MX_TIM3_Init(void);
static void MX_TIM2_Init(void);
static void MX_TIM4_Init(void);
static void MX_TIM5_Init(void);
/* USER CODE BEGIN PFP */
static void ADC_Select_CH(int CH);
/* USER CODE END PFP */

/* USER CODE BEGIN 0 */


void ADC_Select_CH(int CH)
{
    ADC_ChannelConfTypeDef sConfig = {0};
    switch(CH)
    {
        case 0:
            sConfig.Channel = ADC_CHANNEL_0;
            sConfig.Rank = 1;
            if (HAL_ADC_ConfigChannel(&hadc1, &sConfig) != HAL_OK)
            {
                Error_Handler();
            }
            break;
        case 1:
            sConfig.Channel = ADC_CHANNEL_1;
            sConfig.Rank = 1;
            if (HAL_ADC_ConfigChannel(&hadc1, &sConfig) != HAL_OK)
            {
                Error_Handler();
            }
            break;
        case 2:
            sConfig.Channel = ADC_CHANNEL_2;
            sConfig.Rank = 1;
            if (HAL_ADC_ConfigChannel(&hadc1, &sConfig) != HAL_OK)
            {
                Error_Handler();
            }
            break;
        case 3:
            sConfig.Channel = ADC_CHANNEL_3;
            sConfig.Rank = 1;
            if (HAL_ADC_ConfigChannel(&hadc1, &sConfig) != HAL_OK)
            {
                Error_Handler();
            }
            break;
        case 4:
            sConfig.Channel = ADC_CHANNEL_4;
            sConfig.Rank = 1;
            if (HAL_ADC_ConfigChannel(&hadc1, &sConfig) != HAL_OK)
            {
                Error_Handler();
            }
            break;
        case 5:
            sConfig.Channel = ADC_CHANNEL_5;
            sConfig.Rank = 1;
            if (HAL_ADC_ConfigChannel(&hadc1, &sConfig) != HAL_OK)
            {
                Error_Handler();
            }
            break;
        case 6:
            sConfig.Channel = ADC_CHANNEL_6;
            sConfig.Rank = 1;
            if (HAL_ADC_ConfigChannel(&hadc1, &sConfig) != HAL_OK)
            {
                Error_Handler();
            }
            break;
        case 7:
            sConfig.Channel = ADC_CHANNEL_7;
            sConfig.Rank = 1;
            if (HAL_ADC_ConfigChannel(&hadc1, &sConfig) != HAL_OK)
            {
                Error_Handler();
            }
            break;
        case 8:
            sConfig.Channel = ADC_CHANNEL_8;
            sConfig.Rank = 1;
            if (HAL_ADC_ConfigChannel(&hadc1, &sConfig) != HAL_OK)
            {
                Error_Handler();
            }
            break;
        case 9:
            sConfig.Channel = ADC_CHANNEL_9;
            sConfig.Rank = 1;
            if (HAL_ADC_ConfigChannel(&hadc1, &sConfig) != HAL_OK)
            {
                Error_Handler();
            }
            break;
        case 10:
            sConfig.Channel = ADC_CHANNEL_10;
            sConfig.Rank = 1;
            if (HAL_ADC_ConfigChannel(&hadc1, &sConfig) != HAL_OK)
            {
                Error_Handler();
            }
            break;
        case 11:
            sConfig.Channel = ADC_CHANNEL_11;
            sConfig.Rank = 1;
            if (HAL_ADC_ConfigChannel(&hadc1, &sConfig) != HAL_OK)
            {
                Error_Handler();
            }
            break;
        case 12:
            sConfig.Channel = ADC_CHANNEL_12;
            sConfig.Rank = 1;
            if (HAL_ADC_ConfigChannel(&hadc1, &sConfig) != HAL_OK)
            {
                Error_Handler();
            }
            break;
        case 13:
            sConfig.Channel = ADC_CHANNEL_13;
            sConfig.Rank = 1;
            if (HAL_ADC_ConfigChannel(&hadc1, &sConfig) != HAL_OK)
            {
                Error_Handler();
            }
            break;
        case 14:
            sConfig.Channel = ADC_CHANNEL_14;
            sConfig.Rank = 1;
            if (HAL_ADC_ConfigChannel(&hadc1, &sConfig) != HAL_OK)
            {
                Error_Handler();
            }
            break;
        case 15:
            sConfig.Channel = ADC_CHANNEL_15;
            sConfig.Rank = 1;
            if (HAL_ADC_ConfigChannel(&hadc1, &sConfig) != HAL_OK)
            {
                Error_Handler();
            }
            break;
    }
}


void DIGITS_Display(uint8_t DIGIT)
{
	uint8_t DIGIT_B = DIGIT % 10;
	uint8_t DIGIT_A = (DIGIT - DIGIT_B) / 10;

	uint8_t DIGITA_VAL = 0x0F & DIGIT_A; //mask off higher4 bits
	 int Abit0 = (DIGITA_VAL ) & 1;  	// extract Abit0 of the 4-bit value
	 int Abit1 = (DIGITA_VAL >> 1) & 1;  // extract Abit1 of the 4-bit value
	 int Abit2 = (DIGITA_VAL >> 2) & 1;  // extract Abit2 of the 4-bit value
	 int Abit3 = (DIGITA_VAL >> 3) & 1;  // extract Abit3 of the 4-bit value

	 uint8_t DIGITB_VAL = 0x0F & DIGIT_B; //mask off higher4 bits
	 int Bbit0 = (DIGITB_VAL ) & 1;  	// extract Bbit0 of the 4-bit value
	 int Bbit1 = (DIGITB_VAL >> 1) & 1;  // extract Bbit1 of the 4-bit value
	 int Bbit2 = (DIGITB_VAL >> 2) & 1;  // extract Bbit2 of the 4-bit value
	 int Bbit3 = (DIGITB_VAL >> 3) & 1;  // extract Bbit3 of the 4-bit value

	 if (Abit0 == (0))
	 {
		 HAL_GPIO_WritePin(GPIOC, DIGIT_A0_Pin, GPIO_PIN_RESET);
	 }
	 else
	 {
		 HAL_GPIO_WritePin(GPIOC, DIGIT_A0_Pin, GPIO_PIN_SET);

	 }
	 if (Abit1 == (0))
	 {
		 HAL_GPIO_WritePin(GPIOC, DIGIT_A1_Pin, GPIO_PIN_RESET);
	 }
	 else
	 {
		 HAL_GPIO_WritePin(GPIOC, DIGIT_A1_Pin, GPIO_PIN_SET);

	 }
	 if (Abit2 == (0))
	 {
		 HAL_GPIO_WritePin(GPIOC, DIGIT_A2_Pin, GPIO_PIN_RESET);
	 }
	 else
	 {
		 HAL_GPIO_WritePin(GPIOC, DIGIT_A2_Pin, GPIO_PIN_SET);

	 }
	 if (Abit3 == (0))
	 {
		 HAL_GPIO_WritePin(GPIOC, DIGIT_A3_Pin, GPIO_PIN_RESET);
	 }
	 else
	 {
		 HAL_GPIO_WritePin(GPIOC, DIGIT_A3_Pin, GPIO_PIN_SET);

	 }


	 if (Bbit0 == (0))
	 {
		 HAL_GPIO_WritePin(GPIOA, DIGIT_B0_Pin, GPIO_PIN_RESET);
	 }
	 else
	 {
		 HAL_GPIO_WritePin(GPIOA, DIGIT_B0_Pin, GPIO_PIN_SET);

	 }
	 if (Bbit1 == (0))
	 {
		 HAL_GPIO_WritePin(GPIOB, DIGIT_B1_Pin, GPIO_PIN_RESET);
	 }
	 else
	 {
		 HAL_GPIO_WritePin(GPIOB, DIGIT_B1_Pin, GPIO_PIN_SET);

	 }
	 if (Bbit2 == (0))
	 {
		 HAL_GPIO_WritePin(GPIOA, DIGIT_B2_Pin, GPIO_PIN_RESET);
	 }
	 else
	 {
		 HAL_GPIO_WritePin(GPIOA, DIGIT_B2_Pin, GPIO_PIN_SET);

	 }
	 if (Bbit3 == (0))
	 {
		 HAL_GPIO_WritePin(GPIOA, DIGIT_B3_Pin, GPIO_PIN_RESET);
	 }
	 else
	 {
		 HAL_GPIO_WritePin(GPIOA, DIGIT_B3_Pin, GPIO_PIN_SET);

	 }
}

void HCSR04_TRIG_PULSE(void)
{
	HAL_GPIO_WritePin(HCSR04_TRIG_GPIO_Port, HCSR04_TRIG_Pin, GPIO_PIN_SET);
	for (int j = 0; j != 48; j = j + 1) {}
	HAL_GPIO_WritePin(HCSR04_TRIG_GPIO_Port, HCSR04_TRIG_Pin, GPIO_PIN_RESET);
	HAL_Delay(30);
}

void MOTOR_Run(int speed)
{
	if(speed >= 0) {
		TIM3->CCR3 = ((float)speed/100)*60000;
		TIM3->CCR1 = 0;
	} else {
		TIM3->CCR1 = ((float)speed/-100)*60000;
		TIM3->CCR3 = 0;
	}
}

void SERVO_Run(int position)
{
	int TIM2_CH1_STEP = 20;
	while(TIM2_CH1_DCVAL != position) {
		if(TIM2_CH1_DCVAL < position){
			TIM2_CH1_DCVAL += TIM2_CH1_STEP;
		}else if (TIM2_CH1_DCVAL > position){
			TIM2_CH1_DCVAL -= TIM2_CH1_STEP;
		}
		TIM2->CCR1 = TIM2_CH1_DCVAL;
		HAL_Delay(5);
	}
}

void RGBLED_Run(uint8_t colour)
{
	switch(colour)
	{
	case 0: // purple
		HAL_GPIO_WritePin(GPIOB, BLU_Pin, GPIO_PIN_SET);
		HAL_GPIO_WritePin(GPIOB, GRN_Pin, GPIO_PIN_RESET);
		HAL_GPIO_WritePin(GPIOB, RED_Pin, GPIO_PIN_SET);
		break;
	case 1: // red
		HAL_GPIO_WritePin(GPIOB, BLU_Pin, GPIO_PIN_RESET);
		HAL_GPIO_WritePin(GPIOB, GRN_Pin, GPIO_PIN_RESET);
		HAL_GPIO_WritePin(GPIOB, RED_Pin, GPIO_PIN_SET);
		break;
	case 2: // green
		HAL_GPIO_WritePin(GPIOB, BLU_Pin, GPIO_PIN_RESET);
		HAL_GPIO_WritePin(GPIOB, GRN_Pin, GPIO_PIN_SET);
		HAL_GPIO_WritePin(GPIOB, RED_Pin, GPIO_PIN_RESET);
		break;
	case 3: // blue
		HAL_GPIO_WritePin(GPIOB, BLU_Pin, GPIO_PIN_SET);
		HAL_GPIO_WritePin(GPIOB, GRN_Pin, GPIO_PIN_RESET);
		HAL_GPIO_WritePin(GPIOB, RED_Pin, GPIO_PIN_RESET);
		break;
	case 4: // none
		HAL_GPIO_WritePin(GPIOB, BLU_Pin, GPIO_PIN_RESET);
		HAL_GPIO_WritePin(GPIOB, GRN_Pin, GPIO_PIN_RESET);
		HAL_GPIO_WritePin(GPIOB, RED_Pin, GPIO_PIN_RESET);
		break;
	case 5: // white
		HAL_GPIO_WritePin(GPIOB, BLU_Pin, GPIO_PIN_SET);
		HAL_GPIO_WritePin(GPIOB, GRN_Pin, GPIO_PIN_SET);
		HAL_GPIO_WritePin(GPIOB, RED_Pin, GPIO_PIN_SET);
		break;
	}
}

int generate_random(int min, int max){
	return (rand() % (max-min+1))+ min;
}
/* USER CODE END 0 */

/**
  * @brief  The application entry point.
  * @retval int
  */
int main(void)
{

  /* MCU Configuration--------------------------------------------------------*/

  /* Reset of all peripherals, Initializes the Flash interface and the Systick. */
  HAL_Init();

  /* Configure the system clock */
  SystemClock_Config();

  /* Initialize all configured peripherals */
  MX_GPIO_Init();
  MX_USART2_UART_Init();
  MX_USART6_UART_Init();
  MX_ADC1_Init();
  MX_TIM3_Init();
  MX_TIM2_Init();
  MX_TIM4_Init();
  MX_TIM5_Init();
  /* USER CODE BEGIN 2 */

  HAL_TIM_Base_Start(&htim2);
  HAL_TIM_PWM_Start(&htim2, TIM_CHANNEL_1);
  TIM3->PSC = 16-1;
  TIM3->ARR = 20000-1;
  TIM3->CCR1 = TIM2_CH1_DCVAL;

  //HAL_TIM_Base_Init(&htim3);
  HAL_TIM_PWM_Start(&htim3, TIM_CHANNEL_1);
  HAL_TIM_PWM_Start(&htim3, TIM_CHANNEL_3);
  TIM3->PSC = 0;
  TIM3->ARR = 60000;
  TIM3->CCR1 = 0;
  TIM3->CCR3 = 0;

  HAL_TIM_Base_Init(&htim4);
  HAL_TIM_Base_Start(&htim4);
  HAL_TIM_IC_Start_IT(&htim4, TIM_CHANNEL_1);

  HAL_TIM_Base_Start_IT(&htim5);
  clock_hours = 0;
  clock_mins = 0;
  clock_secs = 0;
  /* USER CODE END 2 */
  /* Infinite loop */
  /* USER CODE BEGIN WHILE */

  uint8_t pipe_connection[4] = {0};
  uint8_t pipe_pwm_mode[4] = {0};
  uint8_t current_time = 0;
  uint8_t start_time[4] = {0};
  uint8_t end_time[4] = {0};

  sprintf((char*)txd_msg_buffer, "\r\n\nSETUP MODE");
  HAL_UART_Transmit(&huart6, txd_msg_buffer, strlen((char*)txd_msg_buffer), 1000);
  HAL_Delay(500);

  sprintf((char*)txd_msg_buffer,"\r\n\nFIRST PIPELINE CHOICE FOR CONNECTION: ");
  HAL_UART_Transmit(&huart6, txd_msg_buffer, strlen((char*)txd_msg_buffer),1000);
  rcv_intpt_flag = 00;
  HAL_UART_Receive_IT(&huart6, &byte, 1);
  while(rcv_intpt_flag == (00)) {}
  pipe_connection[0] = (byte[0]-'0');
  sprintf((char*)txd_msg_buffer,"\r\nFIRST PIPELINE CHOICE FOR MOTOR PWM: ");
  HAL_UART_Transmit(&huart6, txd_msg_buffer, strlen((char*)txd_msg_buffer),1000);
  rcv_intpt_flag = 00;
  HAL_UART_Receive_IT(&huart6, &byte, 2);
  while(rcv_intpt_flag == (00)) {}
  pipe_pwm_mode[0] = (byte[0]-'0');

  sprintf((char*)txd_msg_buffer,"\r\nSECOND ZONE CHOICE FOR CONNECTION: ");
  HAL_UART_Transmit(&huart6, txd_msg_buffer, strlen((char*)txd_msg_buffer),1000);
  rcv_intpt_flag = 00;
  HAL_UART_Receive_IT(&huart6, &byte, 1);
  while(rcv_intpt_flag == (00)) {}
  pipe_connection[1] = (byte[0]-'0');
  sprintf((char*)txd_msg_buffer,"\r\nSECOND ZONE CHOICE FOR MOTOR PWM: ");
  HAL_UART_Transmit(&huart6, txd_msg_buffer, strlen((char*)txd_msg_buffer),1000);
  rcv_intpt_flag = 00;
  HAL_UART_Receive_IT(&huart6, &byte, 1);
  while(rcv_intpt_flag == (00)) {}
  pipe_pwm_mode[1] = (byte[0]-'0');

  sprintf((char*)txd_msg_buffer,"\r\nTHIRD ZONE CHOICE FOR CONNECTION: ");
  HAL_UART_Transmit(&huart6, txd_msg_buffer, strlen((char*)txd_msg_buffer),1000);
  rcv_intpt_flag = 00;
  HAL_UART_Receive_IT(&huart6, &byte, 1);
  while(rcv_intpt_flag == (00)) {}
  pipe_connection[2] = (byte[0]-'0');
  sprintf((char*)txd_msg_buffer,"\r\nTHIRD ZONE CHOICE FOR MOTOR PWM: ");
  HAL_UART_Transmit(&huart6, txd_msg_buffer, strlen((char*)txd_msg_buffer),1000);
  rcv_intpt_flag = 00;
  HAL_UART_Receive_IT(&huart6, &byte, 1);
  while(rcv_intpt_flag == (00)) {}
  pipe_pwm_mode[2] = (byte[0]-'0');

  sprintf((char*)txd_msg_buffer,"\r\nFOURTH ZONE CHOICE FOR CONNECTION: ");
  HAL_UART_Transmit(&huart6, txd_msg_buffer, strlen((char*)txd_msg_buffer),1000);
  rcv_intpt_flag = 00;
  HAL_UART_Receive_IT(&huart6, &byte, 1);
  while(rcv_intpt_flag == (00)) {}
  pipe_connection[3] = (byte[0]-'0');
  sprintf((char*)txd_msg_buffer,"\r\nFOURTH ZONE CHOICE FOR MOTOR PWM: ");
  HAL_UART_Transmit(&huart6, txd_msg_buffer, strlen((char*)txd_msg_buffer),1000);
  rcv_intpt_flag = 00;
  HAL_UART_Receive_IT(&huart6, &byte, 1);
  while(rcv_intpt_flag == (00)) {}
  pipe_pwm_mode[3] = (byte[0]-'0');


  sprintf((char*)txd_msg_buffer,"\r\n\nCURRENT WALL CLOCK TIME: ");
  HAL_UART_Transmit(&huart6, txd_msg_buffer, strlen((char*)txd_msg_buffer),1000);
  rcv_intpt_flag = 00;
  HAL_UART_Receive_IT(&huart6, &byte, 2);
  while(rcv_intpt_flag == (00)) {}
  current_time = (byte[0] - '0') * 10 + (byte[1] - '0');

  sprintf((char*)txd_msg_buffer,"\r\nINLET WALL CLOCK START TIME: ");
  HAL_UART_Transmit(&huart6, txd_msg_buffer, strlen((char*)txd_msg_buffer),1000);
  rcv_intpt_flag = 00;
  HAL_UART_Receive_IT(&huart6, &byte, 2);
  while(rcv_intpt_flag == (00)) {}
  start_time[0] = (byte[0] - '0') * 10 + (byte[1] - '0');
  sprintf((char*)txd_msg_buffer,"\r\nINLET WALL CLOCK STOP TIME: ");
  HAL_UART_Transmit(&huart6, txd_msg_buffer, strlen((char*)txd_msg_buffer),1000);
  rcv_intpt_flag = 00;
  HAL_UART_Receive_IT(&huart6, &byte, 2);
  while(rcv_intpt_flag == (00)) {}
  end_time[0] = (byte[0] - '0') * 10 + (byte[1] - '0');

  sprintf((char*)txd_msg_buffer,"\r\nFIRST ZONE CHOICE WALL CLOCK START TIME: ");
  HAL_UART_Transmit(&huart6, txd_msg_buffer, strlen((char*)txd_msg_buffer),1000);
  rcv_intpt_flag = 00;
  HAL_UART_Receive_IT(&huart6, &byte, 2);
  while(rcv_intpt_flag == (00)) {}
  start_time[1] = (byte[0] - '0') * 10 + (byte[1] - '0');
  sprintf((char*)txd_msg_buffer,"\r\nFIRST ZONE CHOICE WALL CLOCK STOP TIME: ");
  HAL_UART_Transmit(&huart6, txd_msg_buffer, strlen((char*)txd_msg_buffer),1000);
  rcv_intpt_flag = 00;
  HAL_UART_Receive_IT(&huart6, &byte, 2);
  while(rcv_intpt_flag == (00)) {}
  end_time[1] = (byte[0] - '0') * 10 + (byte[1] - '0');

  sprintf((char*)txd_msg_buffer,"\r\nSECOND ZONE CHOICE WALL CLOCK START TIME: ");
  HAL_UART_Transmit(&huart6, txd_msg_buffer, strlen((char*)txd_msg_buffer),1000);
  rcv_intpt_flag = 00;
  HAL_UART_Receive_IT(&huart6, &byte, 2);
  while(rcv_intpt_flag == (00)) {}
  start_time[2] = (byte[0] - '0') * 10 + (byte[1] - '0');
  sprintf((char*)txd_msg_buffer,"\r\nSECOND ZONE CHOICE WALL CLOCK STOP TIME: ");
  HAL_UART_Transmit(&huart6, txd_msg_buffer, strlen((char*)txd_msg_buffer),1000);
  rcv_intpt_flag = 00;
  HAL_UART_Receive_IT(&huart6, &byte, 2);
  while(rcv_intpt_flag == (00)) {}
  end_time[2] = (byte[0] - '0') * 10 + (byte[1] - '0');

  sprintf((char*)txd_msg_buffer,"\r\nTHIRD ZONE CHOICE WALL CLOCK START TIME: ");
  HAL_UART_Transmit(&huart6, txd_msg_buffer, strlen((char*)txd_msg_buffer),1000);
  rcv_intpt_flag = 00;
  HAL_UART_Receive_IT(&huart6, &byte, 2);
  while(rcv_intpt_flag == (00)) {}
  start_time[3] = (byte[0] - '0') * 10 + (byte[1] - '0');

  sprintf((char*)txd_msg_buffer,"\r\nTHIRD ZONE CHOICE WALL CLOCK STOP TIME: ");
  HAL_UART_Transmit(&huart6, txd_msg_buffer, strlen((char*)txd_msg_buffer),1000);
  rcv_intpt_flag = 00;
  HAL_UART_Receive_IT(&huart6, &byte, 2);
  while(rcv_intpt_flag == (00)) {}
  end_time[3] = (byte[0] - '0') * 10 + (byte[1] - '0');

  /*
  pipe_connection[0] = 1;
  pipe_connection[1] = 0;
  pipe_connection[2] = 2;
  pipe_connection[3] = 3;
  pipe_pwm_mode[0] = 0;
  pipe_pwm_mode[1] = 0;
  pipe_pwm_mode[2] = 0;
  pipe_pwm_mode[3] = 0;
  start_time[0] = 0;
  start_time[1] = 2;
  start_time[2] = 4;
  start_time[3] = 6;
  end_time[0] = 2;
  end_time[1] = 4;
  end_time[2] = 6;
  end_time[3] = 8;
  current_time = 0;
  */

  sprintf((char*)txd_msg_buffer,"\r\n\nPRESS BLUE BUTTON TO PRECEED TO RUN MODE");
  HAL_UART_Transmit(&huart6, txd_msg_buffer, strlen((char*)txd_msg_buffer),1000);
  while(HAL_GPIO_ReadPin(GPIOC, B1_Pin)){
	  HAL_GPIO_WritePin(GPIOA, LD2_Pin, GPIO_PIN_SET);
	  HAL_Delay(500);
	  HAL_GPIO_WritePin(GPIOA, LD2_Pin, GPIO_PIN_RESET);
	  HAL_Delay(500);
  }

  sprintf((char*)txd_msg_buffer,"\r\n\nRUN MODE");
  HAL_UART_Transmit(&huart6, txd_msg_buffer, strlen((char*)txd_msg_buffer),1000);
  HAL_GPIO_WritePin(GPIOA, LD2_Pin, GPIO_PIN_SET);


  clock_hours = current_time;
  clock_mins = 0;
  clock_secs = 0;
  wall_clock_hr_update_flag = 1;

  int zone = 0;
  int motor_speed = 0;
  int servo_position[4] = {1000, 1500, 2000, 2500};


    while (1)
    {
    	//potentiometer code
    	ADC_Select_CH(9);
    	HAL_ADC_Start(&hadc1);
    	HAL_ADC_PollForConversion(&hadc1, 1000);
    	uint8_t ADC_CH9 = HAL_ADC_GetValue(&hadc1);
    	HAL_ADC_Stop(&hadc1);

    	current_time = clock_hours;

    	hcsr04_Rx_flag = 0;
    	first_edge = 0;
    	time_edge1 = 0;
    	time_edge2 = 0;
    	time_diff = 0;

    	HCSR04_TRIG_PULSE();
    	while(hcsr04_Rx_flag == 0){};
    	time_diff = time_edge2-time_edge1;
    	distance = (float)time_diff/54;
    	filled = 100-((((float)distance-top_distance)/(bottom_distance-top_distance))*100);
    	sprintf((char*)txd_msg_buffer,"\r\n %d and %d", distance, filled);
    	    			HAL_UART_Transmit(&huart6, txd_msg_buffer, strlen((char*)txd_msg_buffer),1000);


    	if (filled>99) {
    		filled = 99;
    	} else if (filled<0) {
    		filled = 0;
    		empty = 1;
    	}
    	DIGITS_Display(filled);

    	//maybe need to wait until sensor shows 99

    		if(current_time >= start_time[zone] && current_time < end_time[zone]){
    			RGBLED_Run(pipe_connection[zone]);
    			SERVO_Run(servo_position[pipe_connection[zone]]);
    		    switch(pipe_pwm_mode[zone])
    		    {
    		    case 0:
    		    	motor_speed = (((float)ADC_CH9/255)*100);
    		    	rpm = generate_random(((float)ADC_CH9/255)*400,((float)ADC_CH9/255)*500);
    		    	break;
    		    case 1:
    		    	motor_speed = 70;
    		    	rpm = generate_random(325,375);
    		    	break;
    		    case 2:
    		    	motor_speed = 85;
    		    	rpm = generate_random(375,425);
    		    	break;
    		    case 3:
    		    	motor_speed = 99;
    		    	rpm = generate_random(425,475);
    		    	break;
    		    }
    		    if(pipe_connection[zone] == 0){
    		        //motor_speed *= -1;
    		    }
    		    MOTOR_Run(motor_speed);
    		} else if(current_time >= end_time[zone]){
    			zone++;
    		}

    	if(wall_clock_hr_update_flag ==1){


    		if(empty == 1 || zone > 3){
    			sprintf((char*)txd_msg_buffer,"\r\nRESEVOIR EMPTY");
    			HAL_UART_Transmit(&huart6, txd_msg_buffer, strlen((char*)txd_msg_buffer),1000);
    			MOTOR_Run(0);
    			TIM3->CCR1 = 0;
    			TIM3->CCR3 = 0;
    			HAL_GPIO_WritePin(GPIOA, LD2_Pin,GPIO_PIN_SET);
    			while(1)
    			{
    				RGBLED_Run(5);
    				HAL_Delay(500);
    				RGBLED_Run(4);
    				HAL_Delay(500);
    			}
    		}



			sprintf((char*)txd_msg_buffer,"\r\nHour: %d | Zone %d | Motor Speed: %d | Motor RPM: %d | Water Reservoir Depth %d |", clock_hours, zone, motor_speed, rpm, filled);
			HAL_UART_Transmit(&huart6, txd_msg_buffer, strlen((char*)txd_msg_buffer),1000);
			wall_clock_hr_update_flag = 0;
    	}
      /*

  	  // Potentiometer with dc motor code
  	  TIM3_DCVAL = ((float)ADC_CH9/255)*60000;
  	  TIM3->CCR1 = (int)TIM3_DCVAL;

  	  sprintf((char*)txd_msg_buffer, "RPM COUNT: %d \r \n", rpm_tick_count);
  	  HAL_UART_Transmit(&huart6,txd_msg_buffer, strlen((char*)txd_msg_buffer), 1000);


	  //dc motor code
	  TIM3->CCR1 = (int)TIM3_DCVAL;
	  rcv_intpt_flag = 00;
	  HAL_UART_Receive_IT(&huart6, &byte, 1);
	  HAL_UART_Transmit(&huart6,txd_msg_buffer, strlen((char*)txd_msg_buffer), 1000);
	  while(rcv_intpt_flag == (00)) {}
	  */
    /* USER CODE END WHILE */

    /* USER CODE BEGIN 3 */
  }
  /* USER CODE END 3 */
}

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
/* USER CODE BEGIN 4 */
void HAL_UART_RxCpltCallback(UART_HandleTypeDef *huart)
{
    if (huart->Instance == USART6)
    {
        /* Transmit one byte with 100 ms timeout. Transmit the character that was received into the variable called "byte" */
        HAL_UART_Transmit(&huart6, &byte, 1, 100);
        rcv_intpt_flag = 1;
    }
}

void HAL_TIM_IC_CaptureCallback(TIM_HandleTypeDef *htim)
{
if (htim->Instance == TIM4)
    {
        if (htim->Channel == 1) // if the interrupt source is channel 1
        {
            if (first_edge == 0) // if the first value is not captured
            {
                time_edge1 = HAL_TIM_ReadCapturedValue(htim, TIM_CHANNEL_1); // read the first value
                first_edge = 1; // set the first captured as true
            }
   else // if the first is already captured
            {
                time_edge2 = HAL_TIM_ReadCapturedValue(htim, TIM_CHANNEL_1); // read second value
                __HAL_TIM_SET_COUNTER(htim, 0); // reset the counter
                hcsr04_Rx_flag = 1; // set the interrupt flag for result done
            }
        }
    }
}
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

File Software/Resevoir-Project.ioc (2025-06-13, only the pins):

Mcu.UserName=STM32F401RETx
PA0-WKUP.GPIO_Label=DIGIT_B3
PA0-WKUP.Signal=GPIO_Output
PA1.GPIO_Label=DIGIT_B2
PA1.Signal=GPIO_Output
PA11.Signal=USART6_TX
PA12.Signal=USART6_RX
PA13.GPIO_Label=TMS
PA13.Signal=SYS_JTMS-SWDIO
PA14.GPIO_Label=TCK
PA14.Signal=SYS_JTCK-SWCLK
PA15.Signal=S_TIM2_CH1_ETR
PA2.GPIO_Label=USART_TX
PA2.Signal=USART2_TX
PA3.GPIO_Label=USART_RX
PA3.Signal=USART2_RX
PA4.GPIO_Label=DIGIT_B0
PA4.Signal=GPIO_Output
PA5.GPIO_Label=LD2 [Green Led]
PA5.Signal=GPIO_Output
PA6.Signal=S_TIM3_CH1
PB0.GPIO_Label=DIGIT_B1
PB0.Signal=GPIO_Output
PB1.Signal=SharedAnalog_PB1
PB10.GPIO_Label=BLU
PB10.Signal=GPIO_Output
PB12.GPIO_Label=HCSR04_TRIG
PB12.Signal=GPIO_Output
PB2.GPIO_Label=RPM Tick
PB2.Signal=GPXTI2
PB3.GPIO_Label=SWO
PB3.Signal=SYS_JTDO-SWO
PB4.GPIO_Label=GRN
PB4.Signal=GPIO_Output
PB5.GPIO_Label=RED
PB5.Signal=GPIO_Output
PB6.Signal=S_TIM4_CH1
PC0.GPIO_Label=DIGIT_A3
PC0.Signal=GPIO_Output
PC1.GPIO_Label=DIGIT_A2
PC1.Signal=GPIO_Output
PC13-ANTI_TAMP.GPIO_Label=B1 [Blue PushButton]
PC13-ANTI_TAMP.Signal=GPXTI13
PC14-OSC32_IN.Signal=RCC_OSC32_IN
PC15-OSC32_OUT.Signal=RCC_OSC32_OUT
PC2.GPIO_Label=DIGIT_A1
PC2.Signal=GPIO_Output
PC3.GPIO_Label=DIGIT_A0
PC3.Signal=GPIO_Output
PC8.Signal=S_TIM3_CH3

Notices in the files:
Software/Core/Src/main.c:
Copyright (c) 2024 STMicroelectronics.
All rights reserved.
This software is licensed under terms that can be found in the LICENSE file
